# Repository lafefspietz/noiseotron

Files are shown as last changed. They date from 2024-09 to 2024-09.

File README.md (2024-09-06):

# NOISEOTRON

Open source instrument for measuring noise

 - [radio.html](radio.html)
 - [sinewave.html](sinewave.html)
 - [noiseband.html](noiseband.html)
 - [whitenoise.html](whitenoise.html)
 - [quantumnoisetriangle.html](quantumnoisetriangle.html)
 - [quantumsnow.html](quantumsnow.html)
 - [audiospectrum.html](audiospectrum.html)
 - [audiospectrum-2d.html](audiospectrum-2d.html)
 - [webeditor.html](webeditor.html)
 - [geometron/](geometron/)

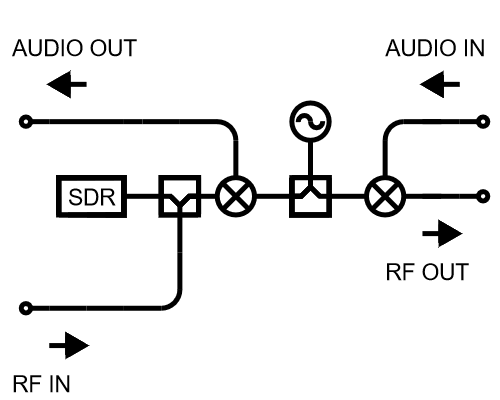
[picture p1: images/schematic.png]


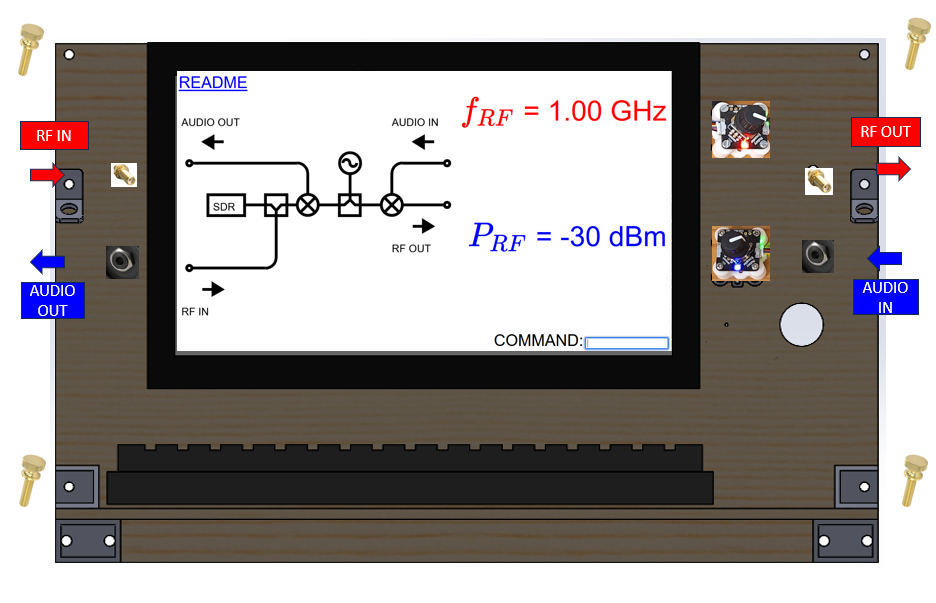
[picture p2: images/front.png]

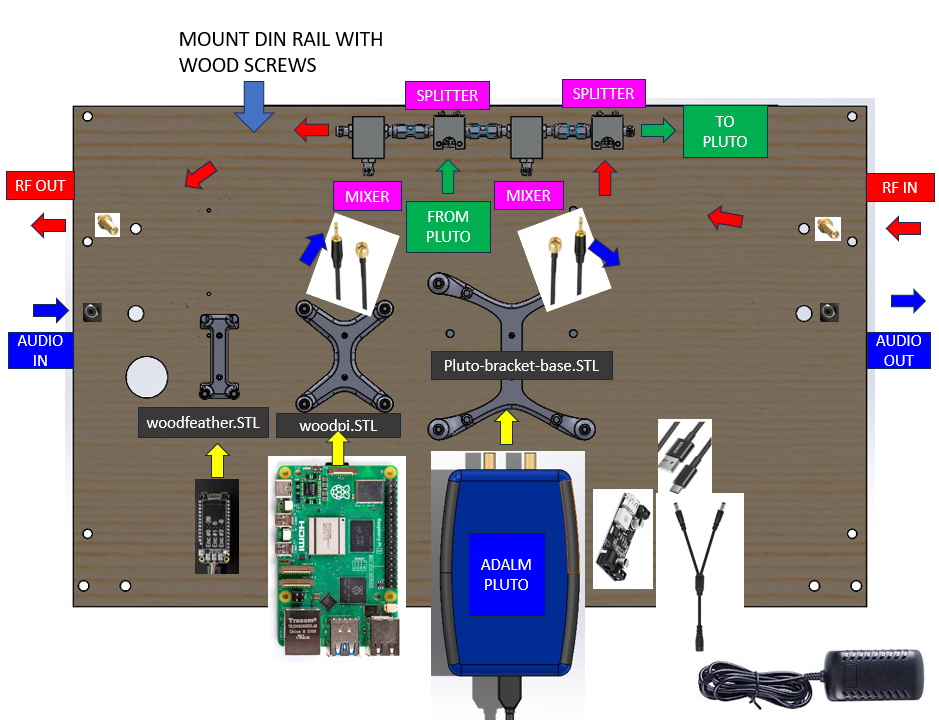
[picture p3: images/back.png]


# Bill of Materials

- [Adalm  Pluto SDR and RF source](https://www.analog.com/en/resources/evaluation-hardware-and-software/evaluation-boards-kits/adalm-pluto.html)
 - [Mini-Circuits ZFRSC-123-S+ 2 way Splitter DC-12 GHz, 50Ω x2](https://www.minicircuits.com/WebStore/dashboard.html?model=ZFRSC-123-S%2B)
 - [Mini-Circuits ZX05-C60-S+ Double Balanced Mixer x2](https://www.minicircuits.com/WebStore/dashboard.html?model=ZX05-C60-S%2B)
 - [Amphenol 132168 M-M SMA Barrel x3](https://www.digikey.com/en/products/detail/amphenol-rf/132168/1011917)
 - [SMA to 1/8" Audio Aux cable from Amazon x2](https://www.amazon.com/supmory-Stereo-Adapter-Antenna-Extension/dp/B0C9JBZ139/)
 - [Audio Panel Mount Feedthru(3/8" hole) x2](https://www.amazon.com/3-5mm-Stereo-Feed-Thru-Panel-Mount/dp/B004JX64FE/)
 - [8" SMA Cable x2](https://www.digikey.com/en/products/detail/crystek-corporation/CCSMA-MM-086-8/2683937)
 - [SMA Panel Mount Feedthru(1/4" hole) x2](https://www.digikey.com/en/products/detail/te-connectivity-linx/ADP-SMAF-SMAF-B-G/11314389)
 - [12"x24" pine board x2](https://www.amazon.com/AWIZOM-Unfinished-Wood-Pine-Rectangular/dp/B0CYQ5PZQX/)
 - [10-32 knurled brass thumb screw x4](https://www.mcmaster.com/92421A645/)
 - [13" wide HDMI Screen from Sunfounder x1](https://www.sunfounder.com/collections/displays-touchscreens-for-raspberry-pi/products/13inch-portable-gaming-monitor)
 - [USB A to C power cable x1](https://www.newegg.com/p/0S8-014F-00215)
 - [12 V to 5 V converter x1](https://www.newegg.com/p/36F-009H-002Z0)
 - [12 V barrel splitter x1](https://www.batteryeliminatorkits.com/product-p/1x2-splitter-cable-long.htm)
 - [Sparkfun QWIIC kit x1](https://www.sparkfun.com/products/15081)
 - [Raspberry Pi 5](https://www.digikey.com/en/products/detail/raspberry-pi/SC1110/24627138)
 - [narrow keyboard](https://www.amazon.com/SR-Keyboard-Multimedia-Computer-Laptop/dp/B01IQL2VCE/)
 - [mouse](https://www.amazon.com/TECKNET-6-Button-Ergonomic-Chromebook-Notebook-Grey/dp/B01BC4TXXC/)
 - [M2.5 Thread inserts](https://www.3djake.com/ruthex/threaded-insert-m25-70-pieces)
 - [M2.5 Screws](https://www.homedepot.com/p/Prime-Line-M2-5-0-45-x-8-mm-Metric-Zinc-Plated-Steel-Phillips-Drive-Pan-Head-Machine-Screws-25-Pack-9130839/311229788)
 - #4 wood screws()
 - [Adafruit Feather](https://www.adafruit.com/product/5300)
 - [Adafruit encoder knob](https://www.adafruit.com/product/4991)

## 3d printed parts

 - [woodpi.STL (x1)]()
 - [woodfeather.STL (x1)]()
 - [stemma-knob-wood-bracket.STL(x2)]()
 - [pluto-bracket-base.STL (x1)]()
 - [pluto-bracket-top-bar.STL (x2)]()
 - [wood-angle-bracket.STL (x2)]()
 - [wood-peg.STL(x6)]()
 - [string-anchor.STL(x2)]()

## stemma-knob-wood-bracket.*

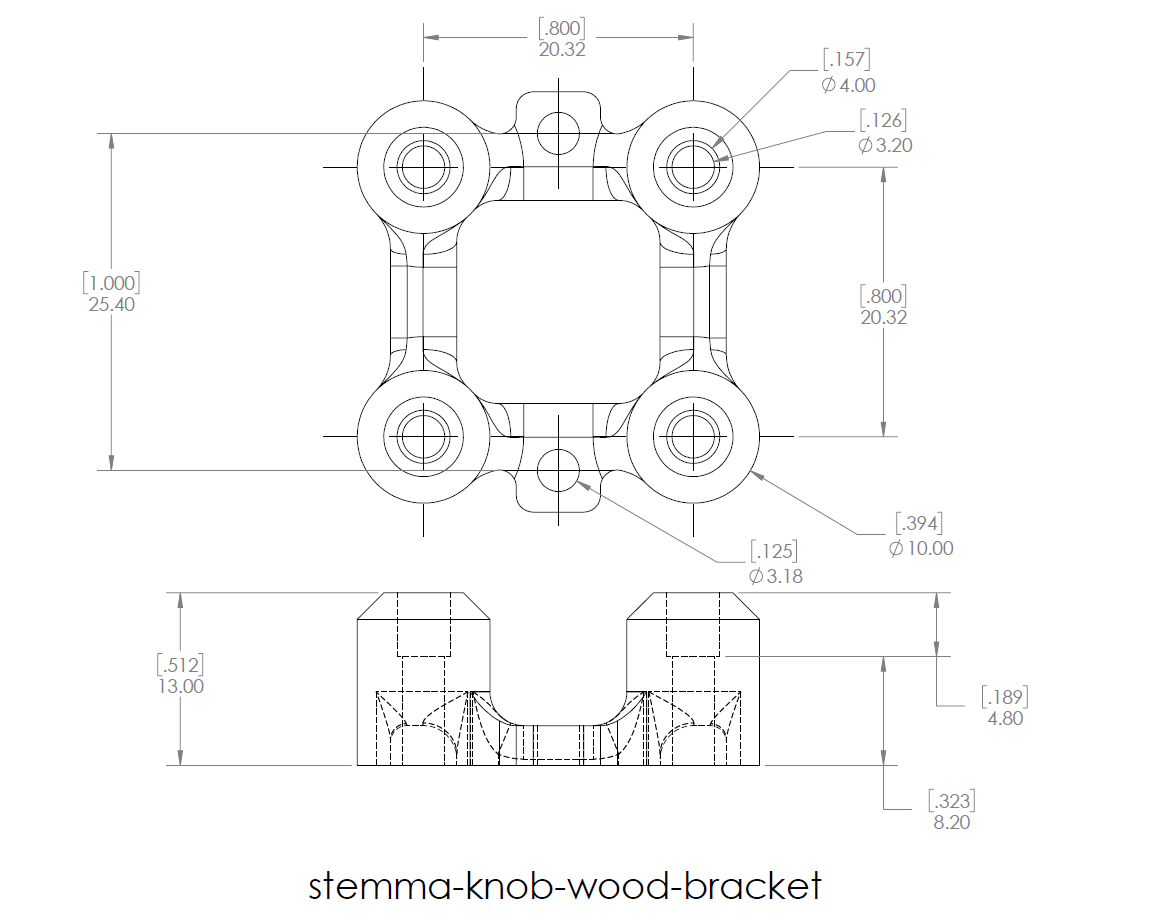
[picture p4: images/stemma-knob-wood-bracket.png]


 - [3dprint/stemma-knob-wood-bracket.STL](3dprint/stemma-knob-wood-bracket.STL)
 - [3dprint/stemma-knob-wood-bracket.SLDPRT](3dprint/stemma-knob-wood-bracket.SLDPRT)
 - [3dprint/stemma-knob-wood-bracket.SLDDRW](3dprint/stemma-knob-wood-bracket.SLDDRW)
 - [3dprint/stemma-knob-wood-bracket.pdf](3dprint/stemma-knob-wood-bracket.pdf)

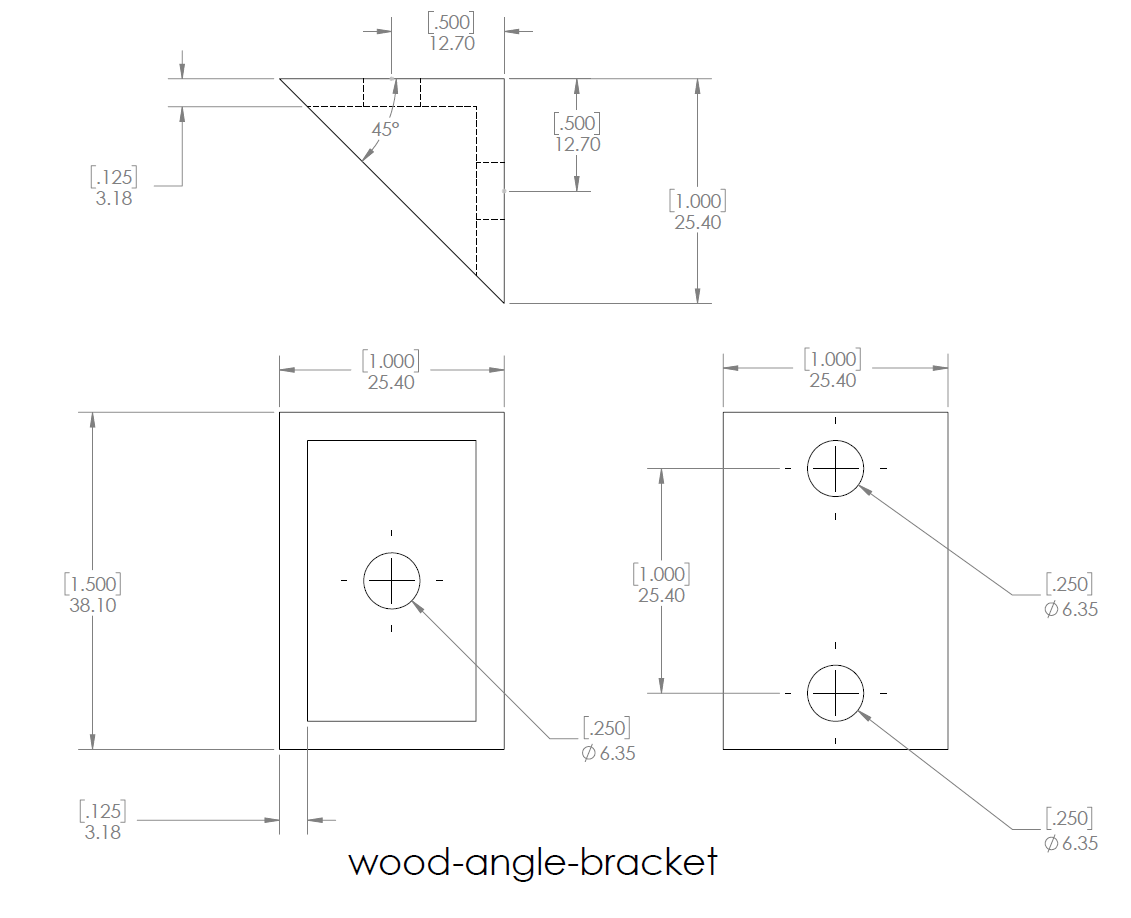
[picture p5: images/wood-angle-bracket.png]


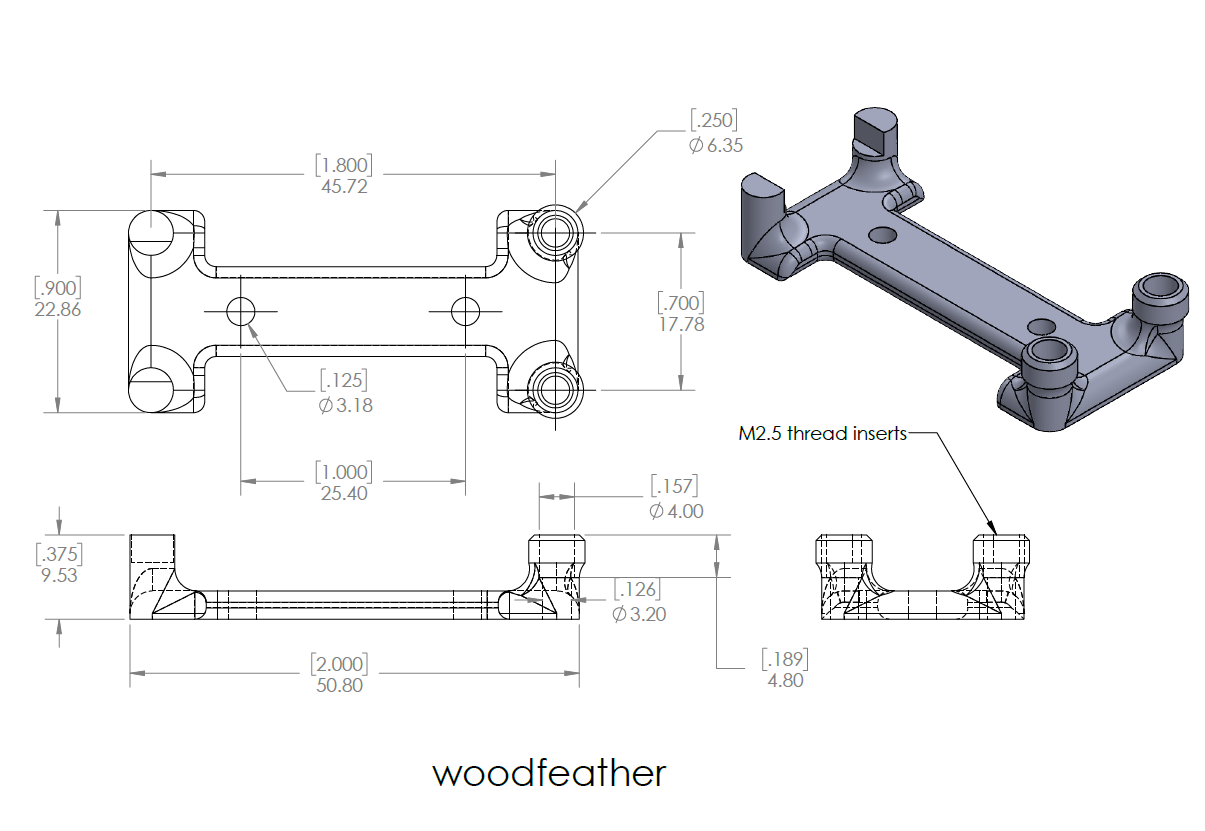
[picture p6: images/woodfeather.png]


# Feather code

 - [All files that go in lib folder in lib.zip](circuitpython/lib.zip)
 - [code.py](circuitpython/code.py)

## Code.py

```

# SPDX-FileCopyrightText: 2021 John Park
# SPDX-License-Identifier: MIT

# I2C rotary encoder multiple test example.
# solder the A0 jumper on the second QT Rotary Encoder board
import time

import board
from adafruit_seesaw import seesaw, rotaryio, digitalio, neopixel
import usb_hid
from adafruit_hid.keyboard import Keyboard
from adafruit_hid.keyboard_layout_us import KeyboardLayoutUS
from adafruit_hid.keycode import Keycode
running = False
# The keyboard object!
time.sleep(1)  # Sleep for a bit to avoid a race condition on some systems
keyboard = Keyboard(usb_hid.devices)
keyboard_layout = KeyboardLayoutUS(keyboard)  # We're in the US :)

i2c = board.I2C()  # uses board.SCL and board.SDA
# i2c = board.STEMMA_I2C()  # For using the built-in STEMMA QT connector on a microcontroller

qt_enc1 = seesaw.Seesaw(i2c, addr=0x36)
qt_enc2 = seesaw.Seesaw(i2c, addr=0x37)

qt_enc1.pin_mode(24, qt_enc1.INPUT_PULLUP)
button1 = digitalio.DigitalIO(qt_enc1, 24)
button_held1 = False

qt_enc2.pin_mode(24, qt_enc2.INPUT_PULLUP)
button2 = digitalio.DigitalIO(qt_enc2, 24)
button_held2 = False

encoder1 = rotaryio.IncrementalEncoder(qt_enc1)
last_position1 = None

encoder2 = rotaryio.IncrementalEncoder(qt_enc2)
last_position2 = None

pixel1 = neopixel.NeoPixel(qt_enc1, 6, 1)
pixel1.brightness = 0.05
pixel1.fill(0xff0000)

pixel2 = neopixel.NeoPixel(qt_enc2, 6, 1)
pixel2.brightness = 0.02
pixel2.fill(0x0000ff)

while True:

    # negate the position to make clockwise rotation positive
    position1 = -encoder1.position
    position2 = -encoder2.position

    if position1 != last_position1:
        last_position1 = position1
        print("Position 1: {}".format(position1))
        keyboard_layout.write("red={}\n".format(position1))

    if not button1.value and not button_held1:
        button_held1 = True
        pixel1.brightness = 0.5
        print("Button 1 pressed")
        keyboard_layout.write("redpress\n")

    if button1.value and button_held1:
        button_held1 = False
        pixel1.brightness = 0.2
        print("Button 1 released")

    if position2 != last_position2:
        last_position2 = position2
        print("Position 2: {}".format(position2))
        keyboard_layout.write("blue={}\n".format(position2))

    if not button2.value and not button_held2:
        button_held2 = True
        pixel2.brightness = 0.5
        print("Button 2 pressed")
        keyboard_layout.write("bluepress\n")

    if button2.value and button_held2:
        button_held2 = False
        pixel2.brightness = 0.2
        print("Button 2 released")

```

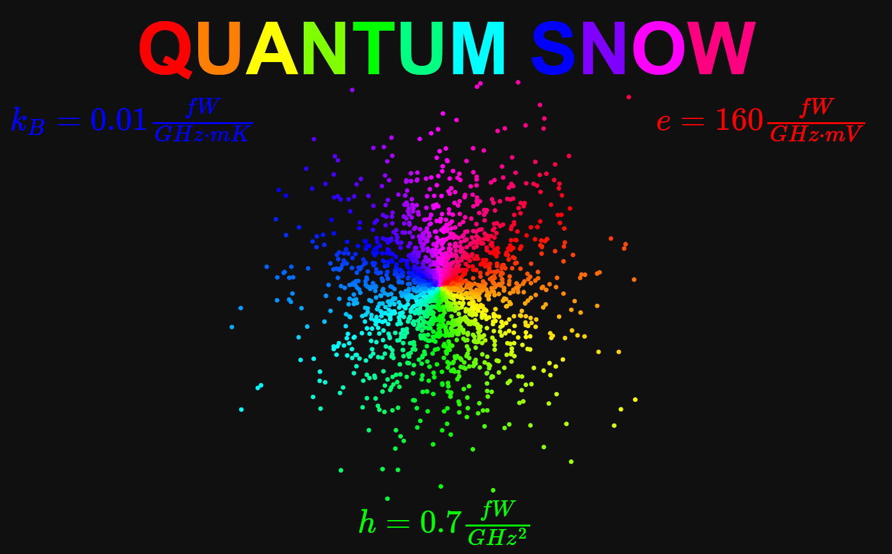
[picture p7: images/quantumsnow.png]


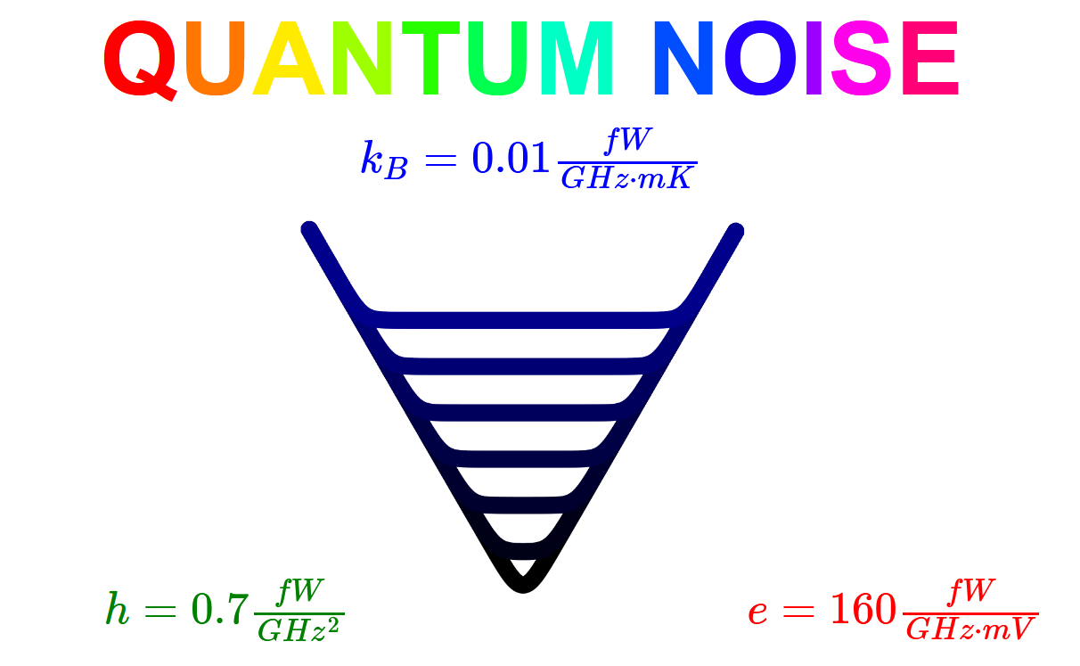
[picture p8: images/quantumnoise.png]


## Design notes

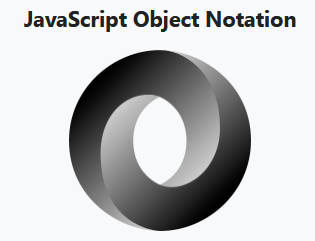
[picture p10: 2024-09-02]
images/json.png

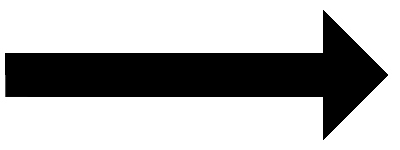
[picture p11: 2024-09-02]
images/longarrow.png

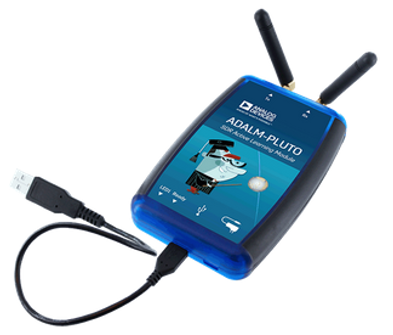
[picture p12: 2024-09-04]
images/pluto.png

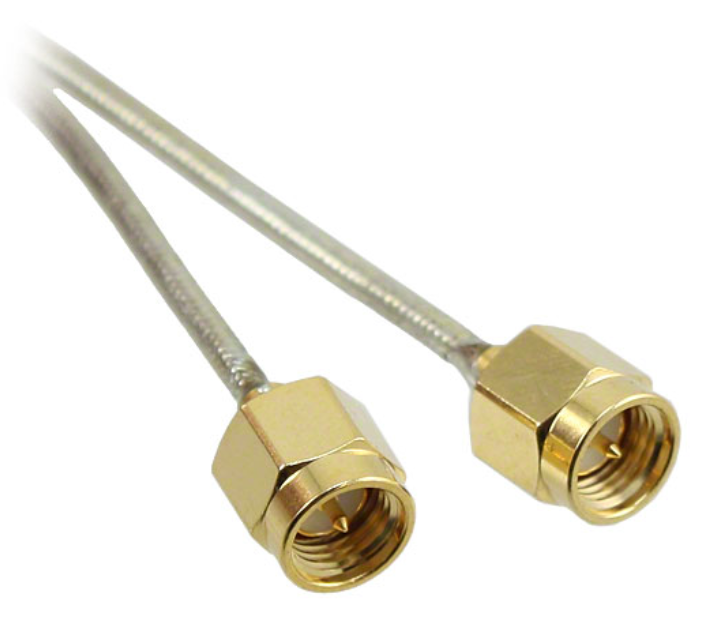
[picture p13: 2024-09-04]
images/sma.png

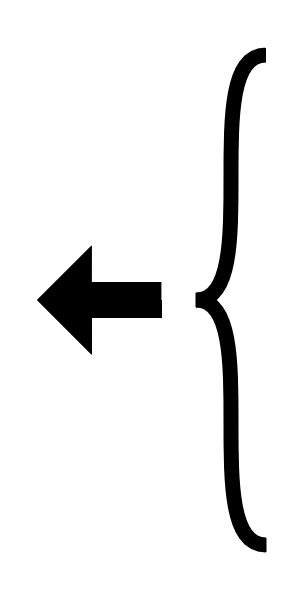
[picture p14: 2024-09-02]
images/joinarrow.png

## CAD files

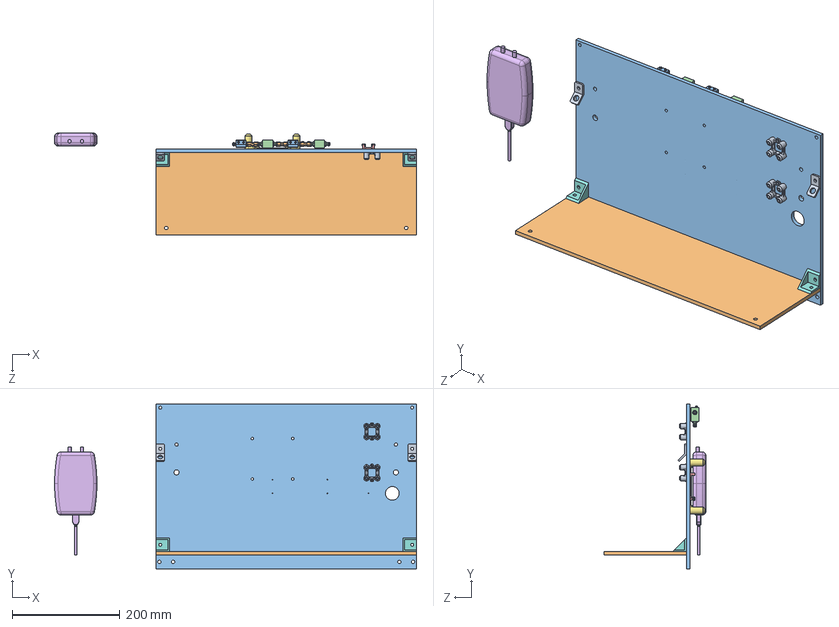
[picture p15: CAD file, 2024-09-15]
rack-mount-assembly.SLDASM
670.6 x 304.8 x 188.3 mm
rack-mount-panel
keyboard-shelf
stemma-knob-wood-bracket x 2
wood-angle-bracket-top x 2
pluto-bracket-base
pluto-box-model
woodfeather
splitter-JJJ245 x 2
mixer-FL905(E) x 2
SMA-barrel-M-M-132168 x 3
string-anchor x 2

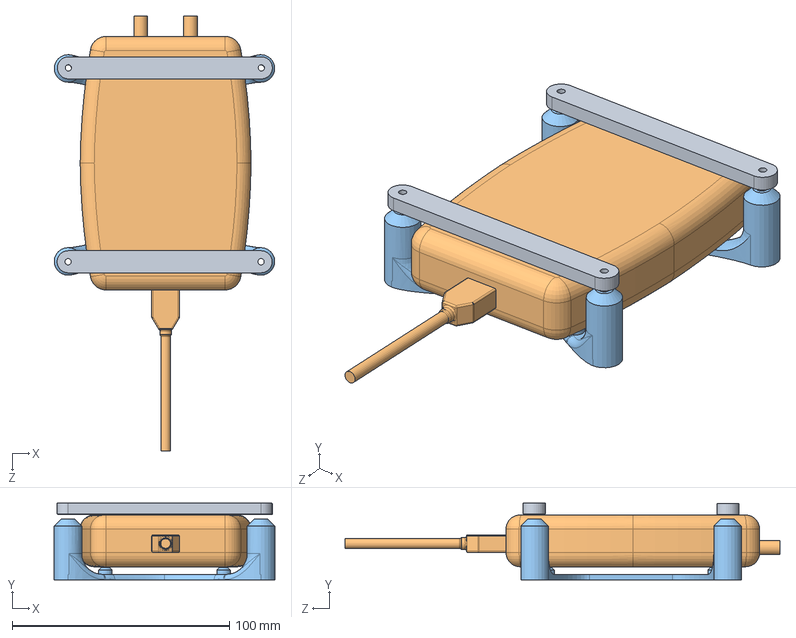
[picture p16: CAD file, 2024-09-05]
pluto-bracket-assembly.SLDASM
101.6 x 35.3 x 200.4 mm
pluto-bracket-base
pluto-box-model
pluto-bracket-top-bar x 2

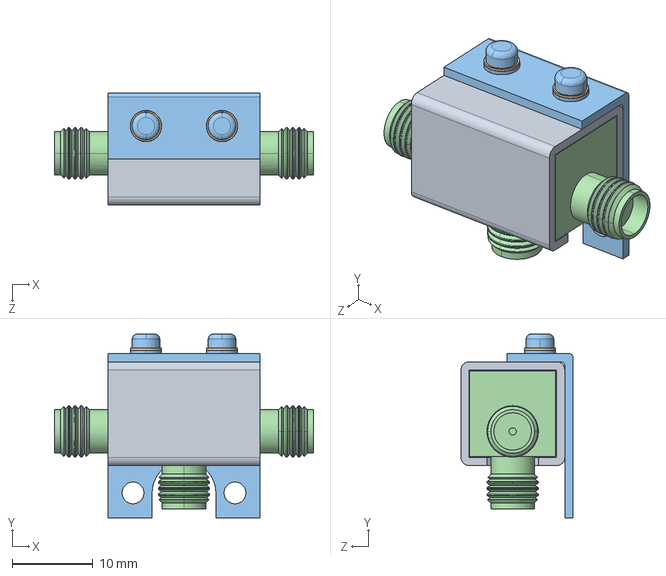
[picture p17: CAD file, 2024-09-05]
3dmodel/FL905(E).STEP
32.0 x 22.7 x 13.8 mm

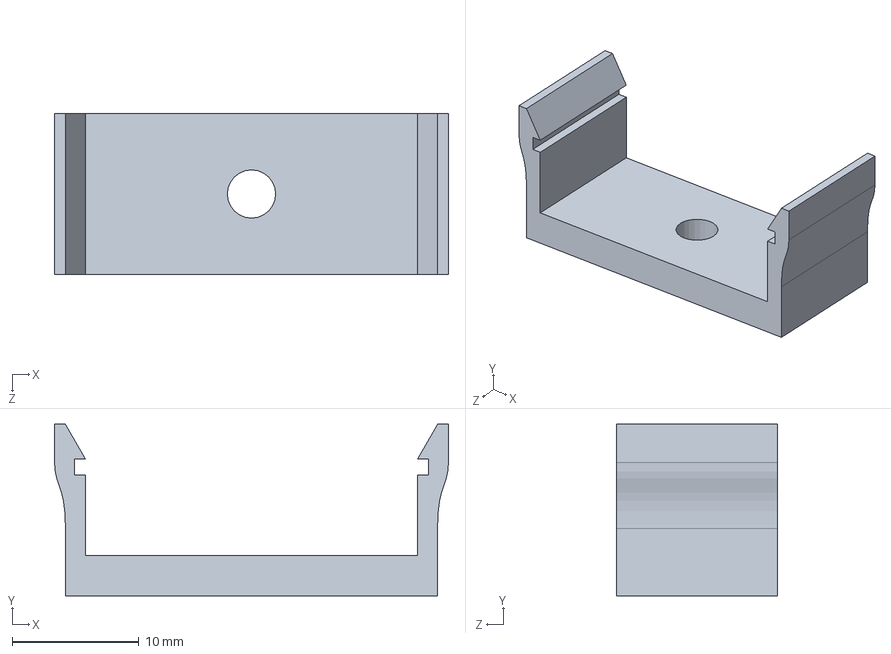
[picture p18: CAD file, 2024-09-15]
3dprint/drok-bracket.SLDPRT
31.1 x 13.5 x 12.7 mm

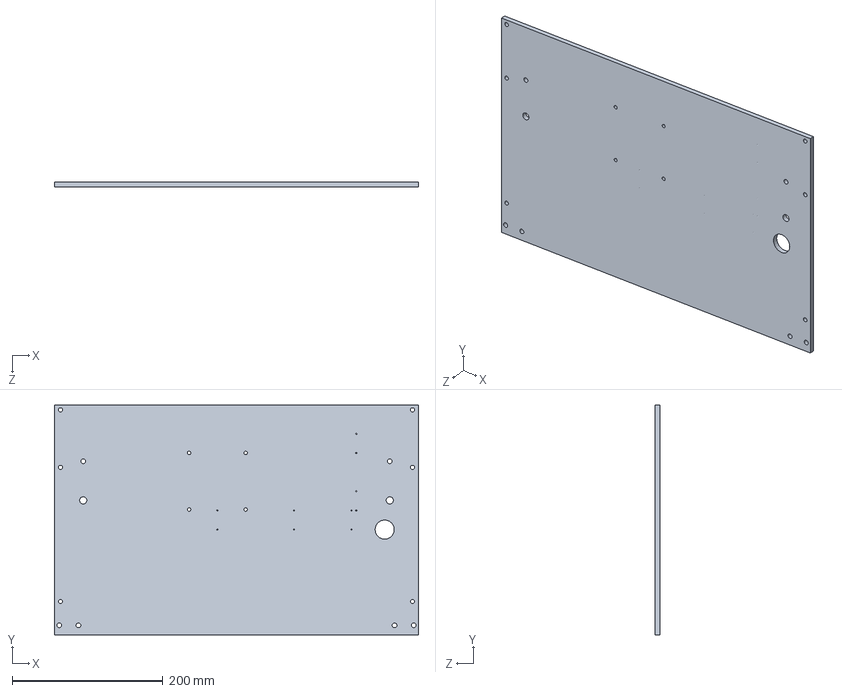
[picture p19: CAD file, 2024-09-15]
wood/rack-mount-panel.SLDPRT
482.6 x 304.8 x 6.35 mm

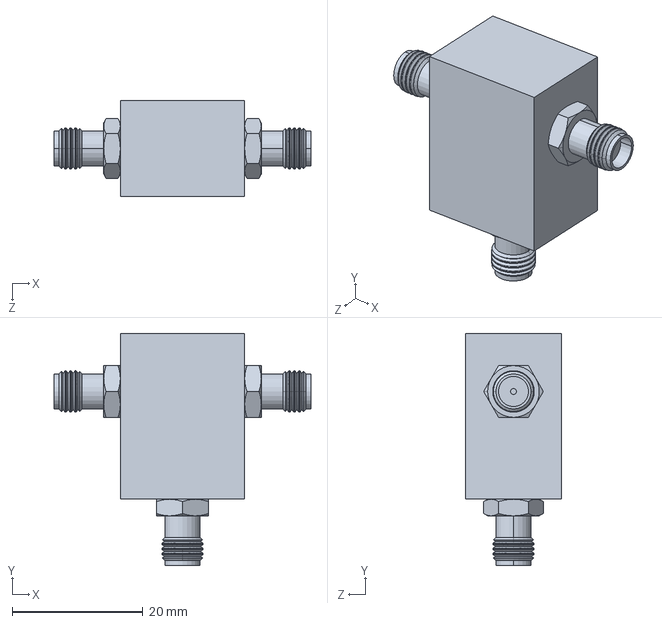
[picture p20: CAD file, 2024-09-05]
3dmodel/splitter-JJJ245.SLDPRT
39.4 x 35.6 x 14.7 mm

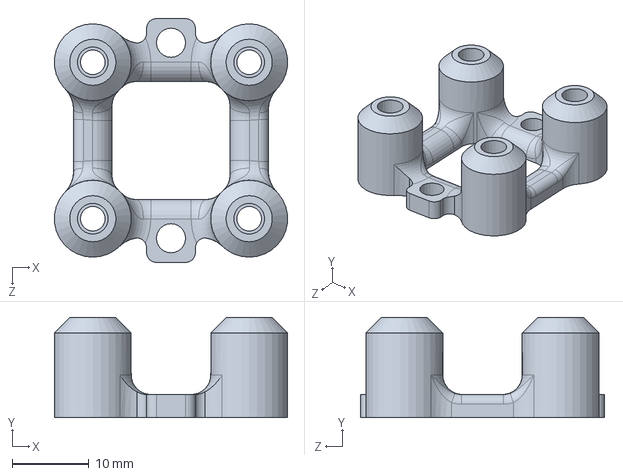
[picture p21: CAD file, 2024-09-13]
3dprint/stemma-knob-wood-bracket.SLDPRT
30.3 x 13.0 x 31.7 mm

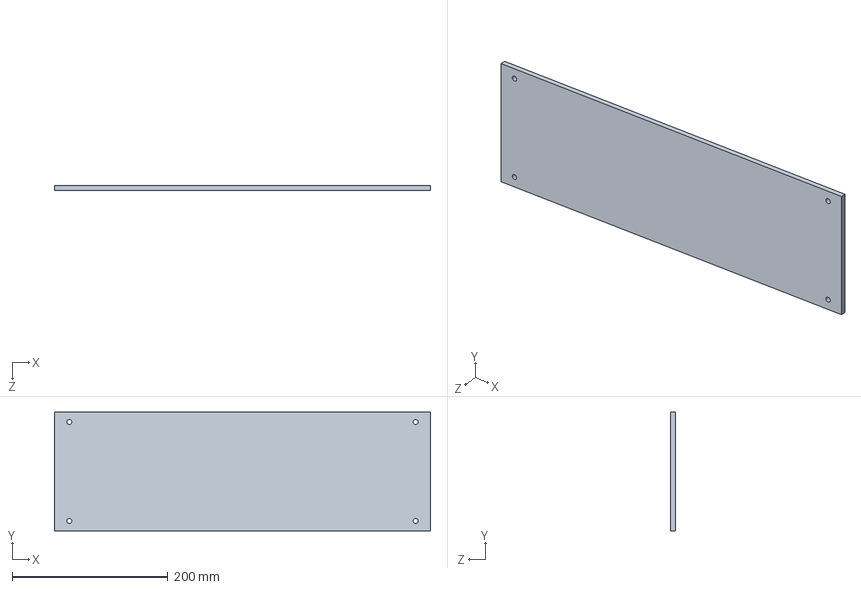
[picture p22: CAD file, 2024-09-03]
wood/keyboard-shelf.SLDPRT
482.6 x 152.4 x 6.35 mm

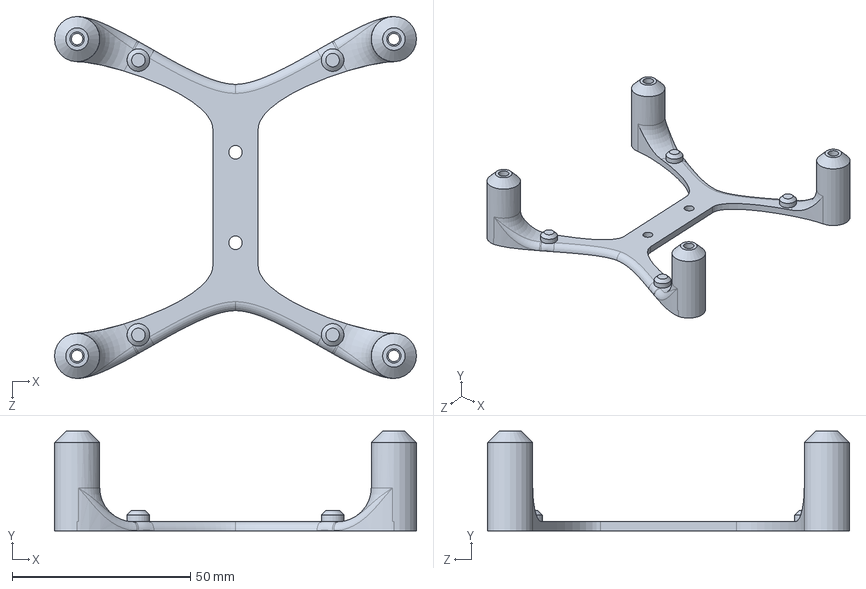
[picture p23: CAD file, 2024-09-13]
3dprint/pluto-bracket-base.SLDPRT
101.6 x 27.9 x 101.6 mm

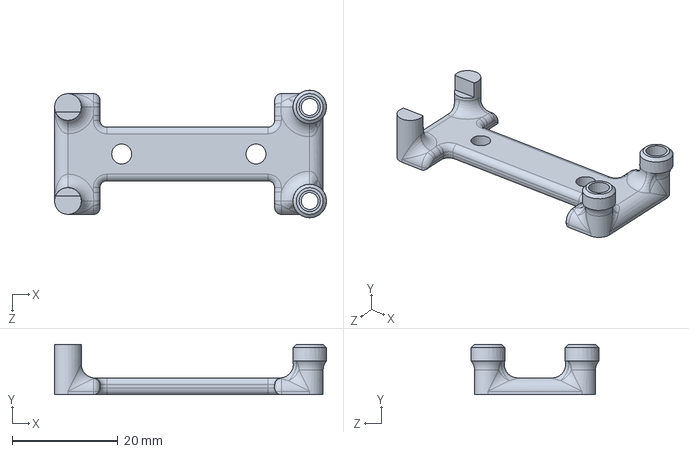
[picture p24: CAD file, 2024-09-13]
3dprint/woodfeather.SLDPRT
51.4 x 9.53 x 24.1 mm

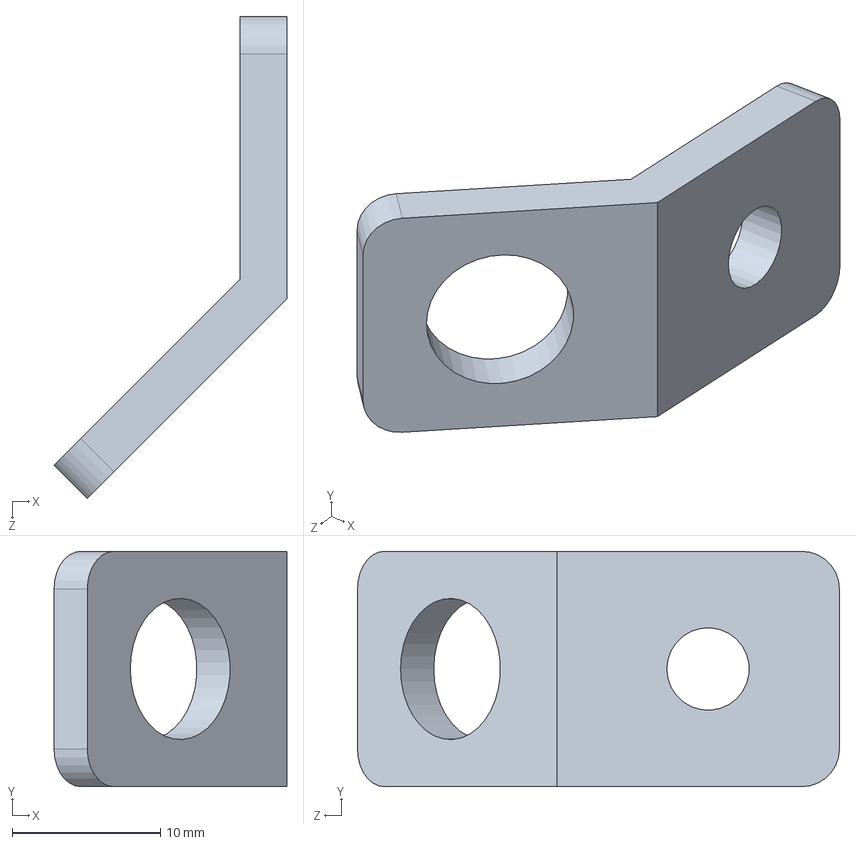
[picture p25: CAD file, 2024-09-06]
3dprint/string-anchor.SLDPRT
15.7 x 15.9 x 32.5 mm

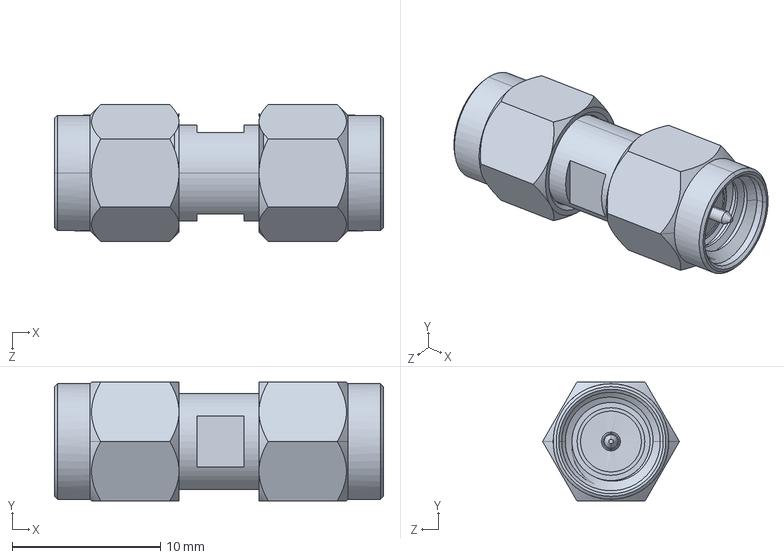
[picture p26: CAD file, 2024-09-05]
3dmodel/SMA-barrel-M-M-132168.SLDPRT
22.2 x 8.00 x 9.24 mm

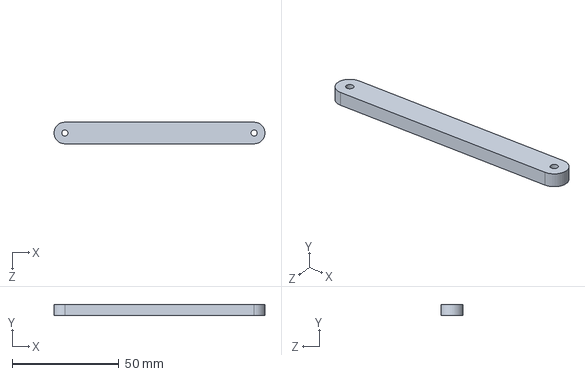
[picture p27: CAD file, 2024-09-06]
3dprint/pluto-bracket-top-bar.SLDPRT
99.1 x 5.08 x 10.2 mm

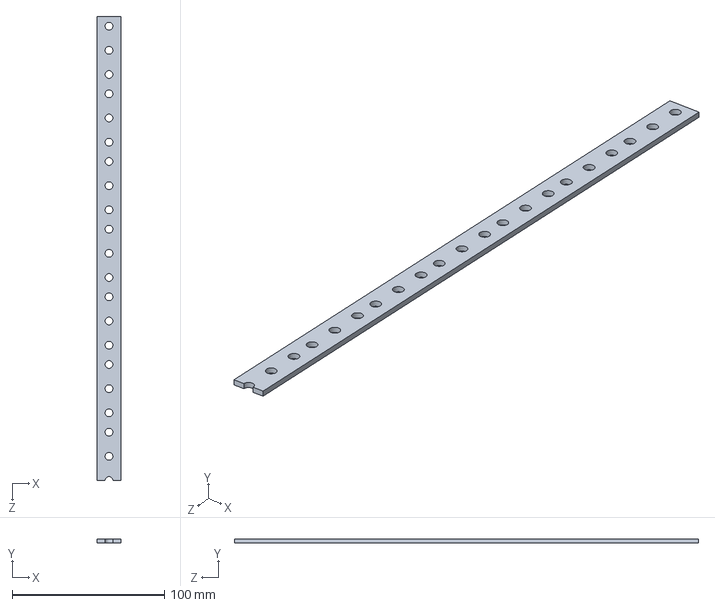
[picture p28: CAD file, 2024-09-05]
3dmodel/rack-side-holes-model.SLDPRT
15.9 x 2.54 x 304.8 mm

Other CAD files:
3dmodel/JJJ245.STEP
3dmodel/mixer-FL905(E).SLDPRT
3dprint/wood-angle-bracket-top.SLDPRT
3dmodel/pluto-box-model.SLDPRT
3dmodel/132168.stp
3dmodel/5300 ESP32-S2 TFT Feather.SLDDRW
3dmodel/5300 ESP32-S2 TFT Feather.step
3dmodel/5300 ESP32-S2 TFT Feather.stl
3dmodel/keyboard.SLDPRT
3dmodel/paracord.SLDPRT
3dmodel/pluto-box-model.SLDDRW
3dmodel/rack-side-holes-model.SLDDRW
3dmodel/screen.SLDPRT
3dprint/drok-bracket.STL
3dprint/pluto-bracket-base.SLDDRW
3dprint/pluto-bracket-base.STL
3dprint/pluto-bracket-top-bar.SLDDRW
3dprint/pluto-bracket-top-bar.STL
3dprint/stemma-knob-wood-bracket.SLDDRW
3dprint/stemma-knob-wood-bracket.STL
3dprint/string-anchor.SLDDRW
3dprint/wood-angle-bracket-top.STL
3dprint/wood-angle-bracket.SLDDRW
3dprint/wood-angle-bracket.SLDPRT
3dprint/wood-angle-bracket.STL
3dprint/wood-peg.SLDDRW
3dprint/wood-peg.SLDPRT
3dprint/wood-peg.STL
3dprint/woodfeather.SLDDRW
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

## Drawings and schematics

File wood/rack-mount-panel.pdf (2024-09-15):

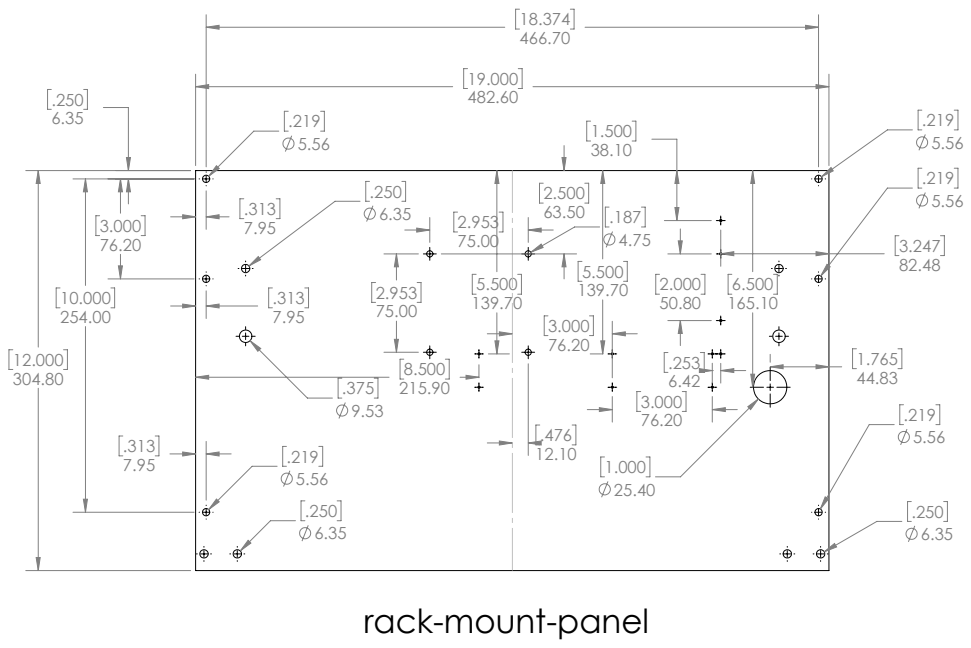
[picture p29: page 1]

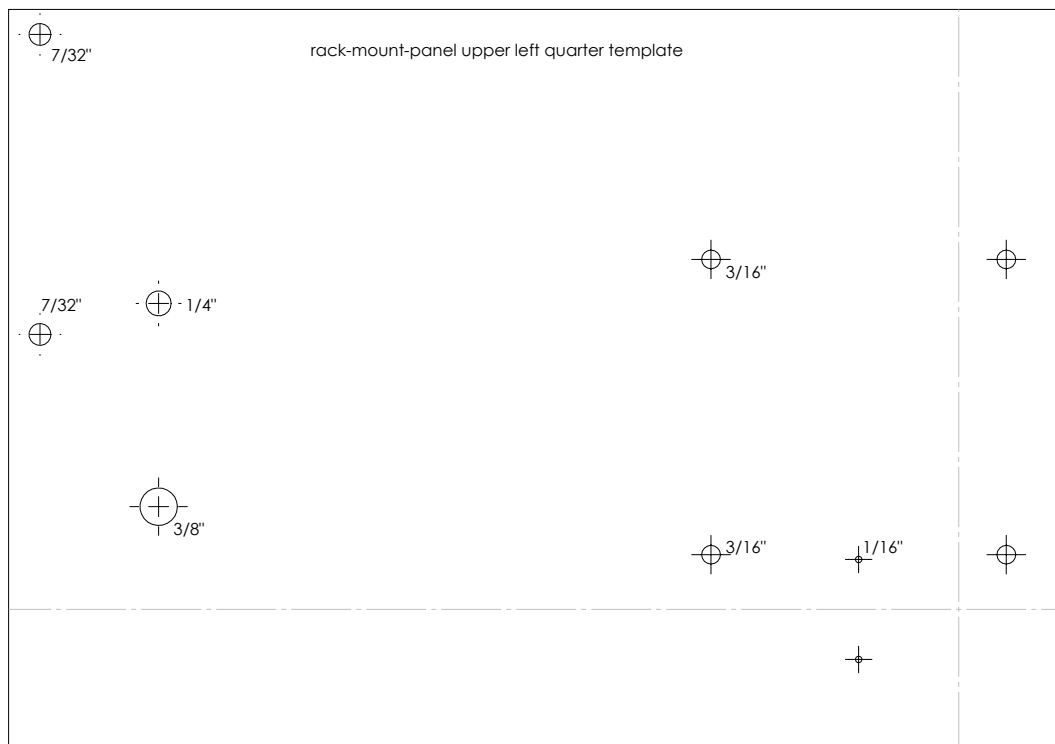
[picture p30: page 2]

rack-mount-panel upper left quarter template

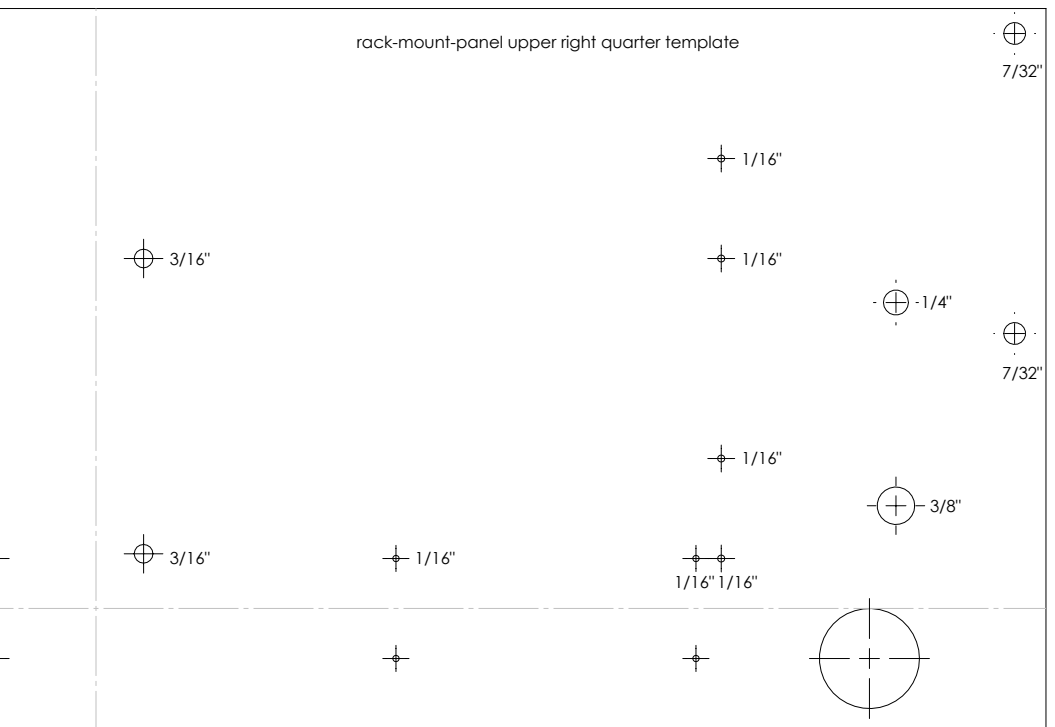
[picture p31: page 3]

rack-mount-panel upper right quarter template

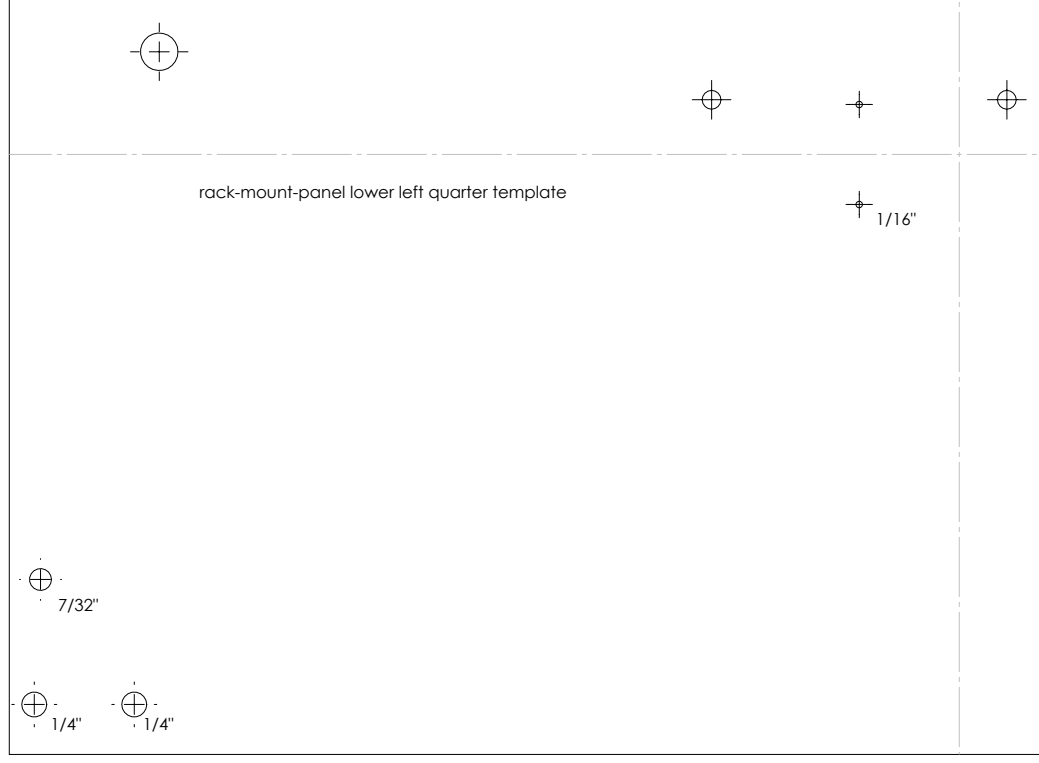
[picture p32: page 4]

rack-mount-panel lower left quarter template

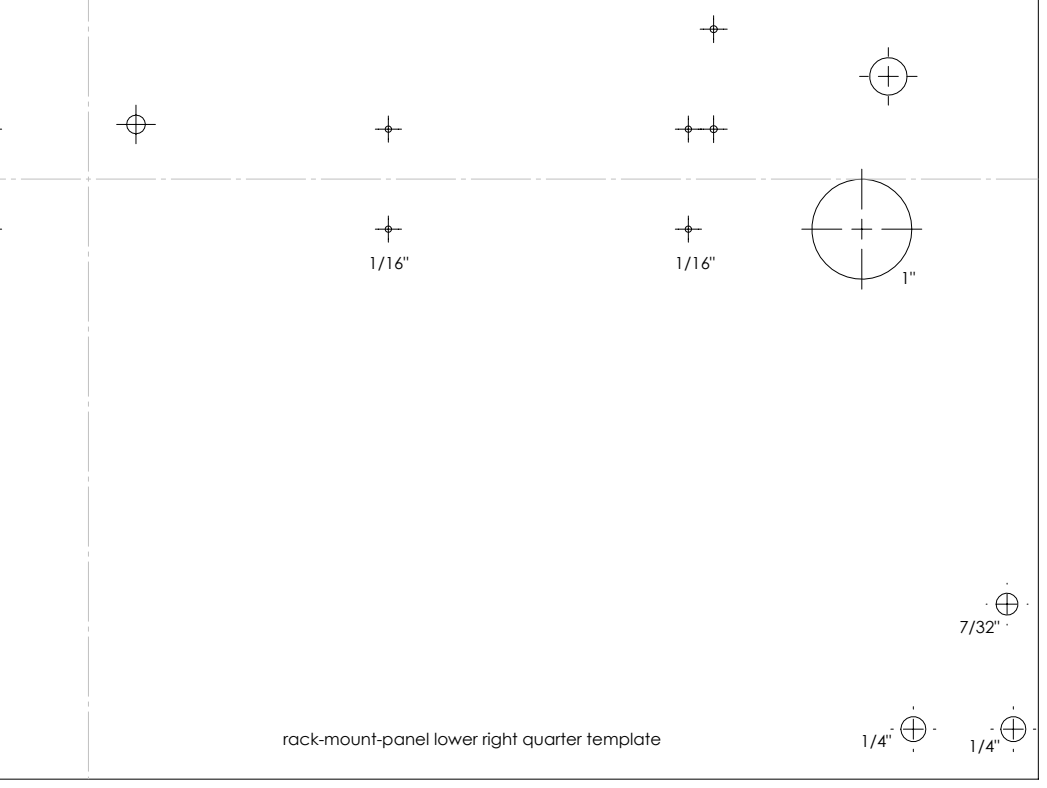
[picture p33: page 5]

rack-mount-panel lower right quarter template

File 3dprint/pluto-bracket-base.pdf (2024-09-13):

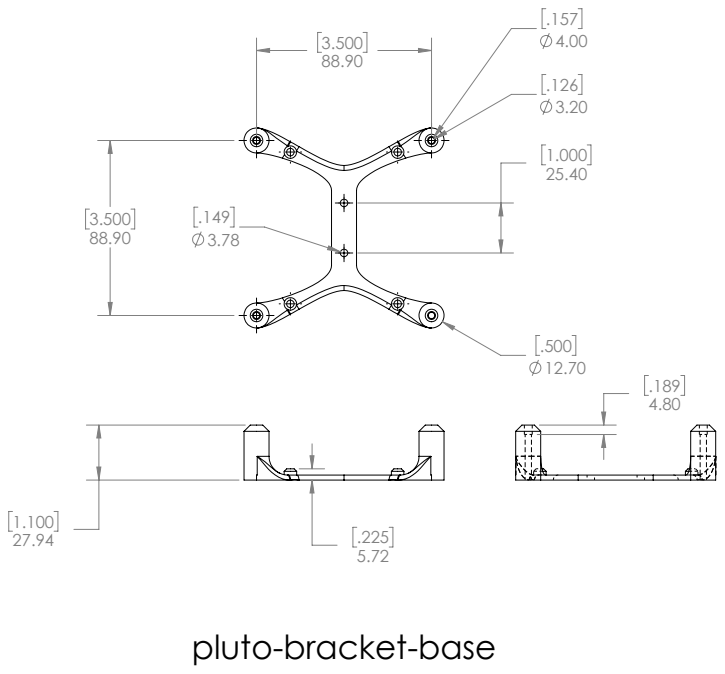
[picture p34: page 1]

pluto-bracket-base

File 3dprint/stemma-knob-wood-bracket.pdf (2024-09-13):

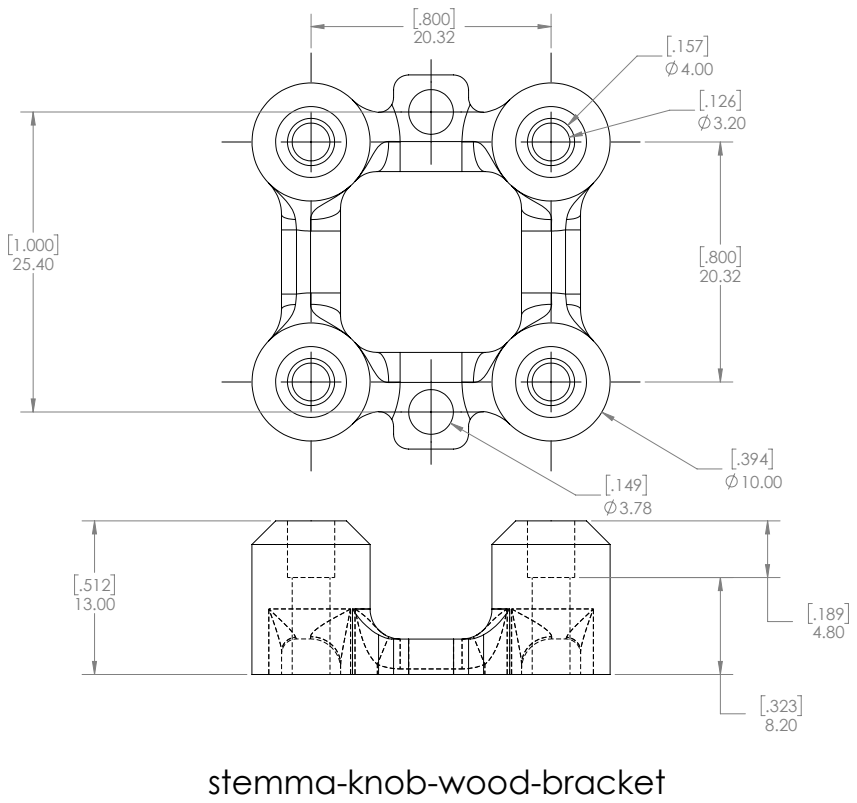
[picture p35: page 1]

stemma-knob-wood-bracket

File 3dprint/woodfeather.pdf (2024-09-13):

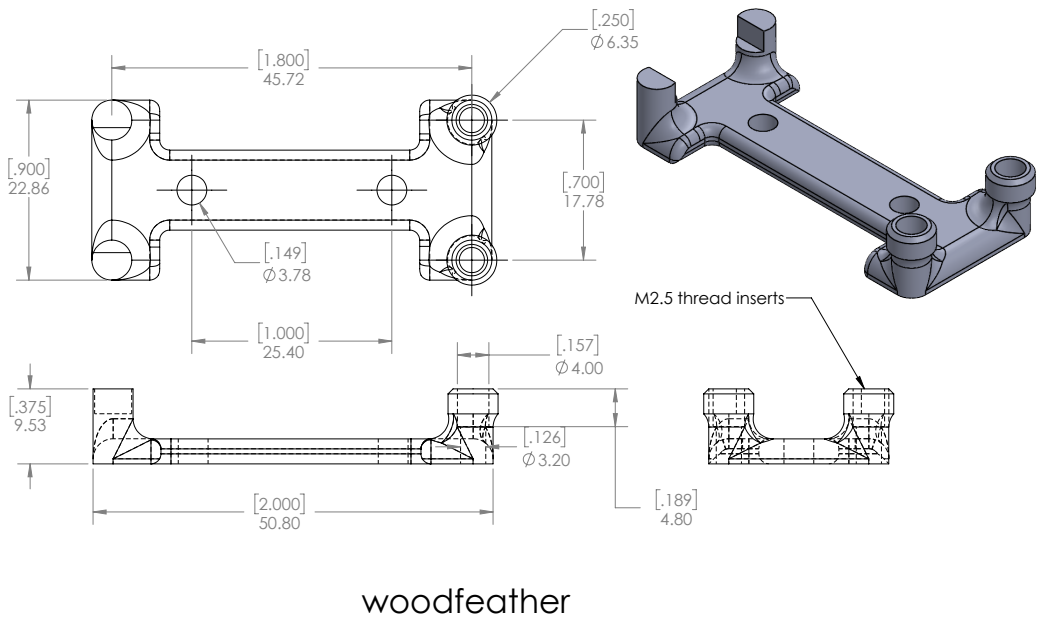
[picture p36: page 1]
M2.5 thread inserts

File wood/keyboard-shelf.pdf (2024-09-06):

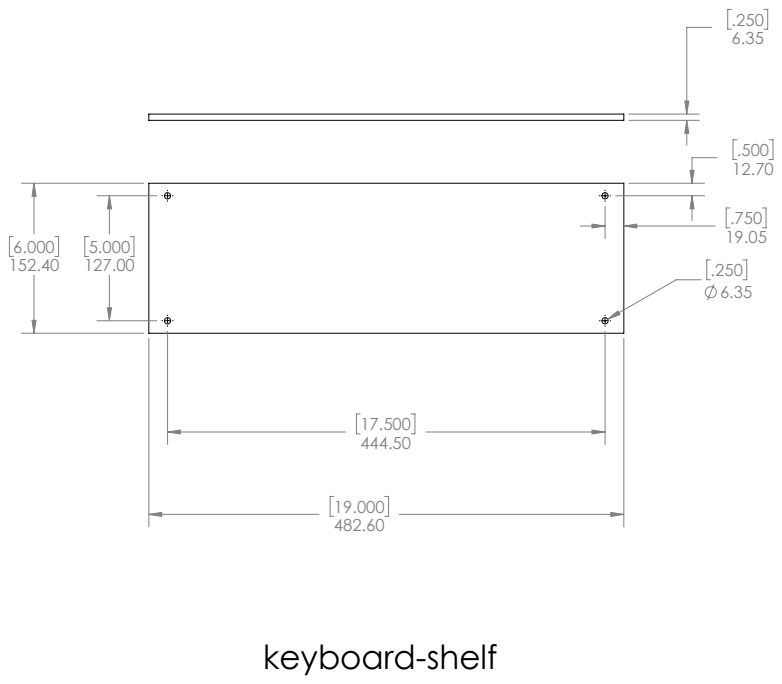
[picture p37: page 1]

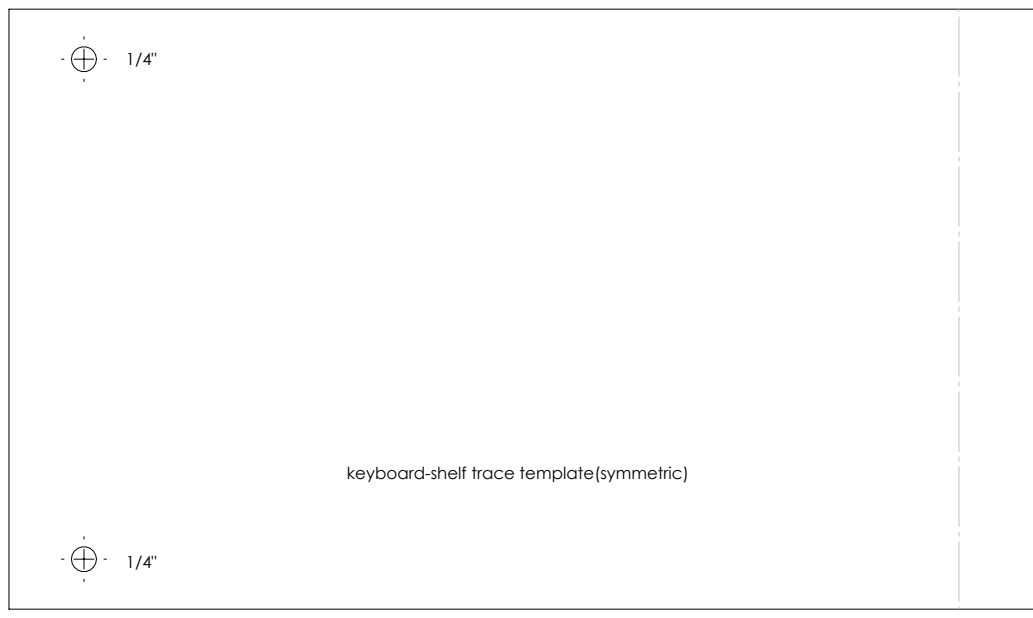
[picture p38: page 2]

keyboard-shelf trace template(symmetric)

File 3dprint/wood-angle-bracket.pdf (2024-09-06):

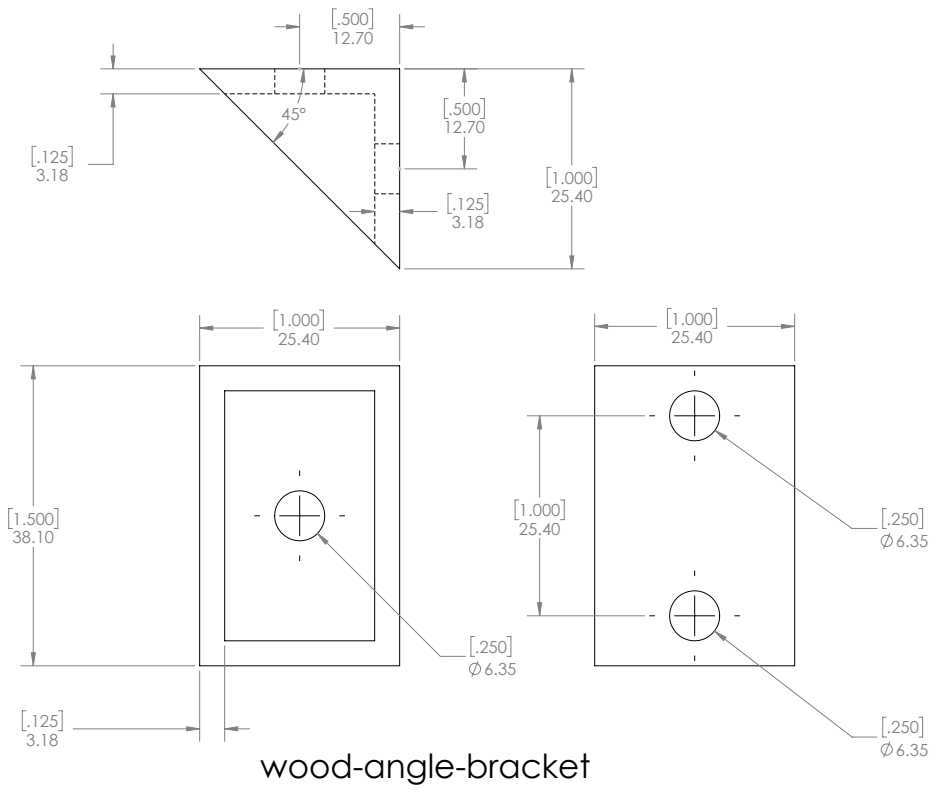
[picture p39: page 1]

wood-angle-bracket

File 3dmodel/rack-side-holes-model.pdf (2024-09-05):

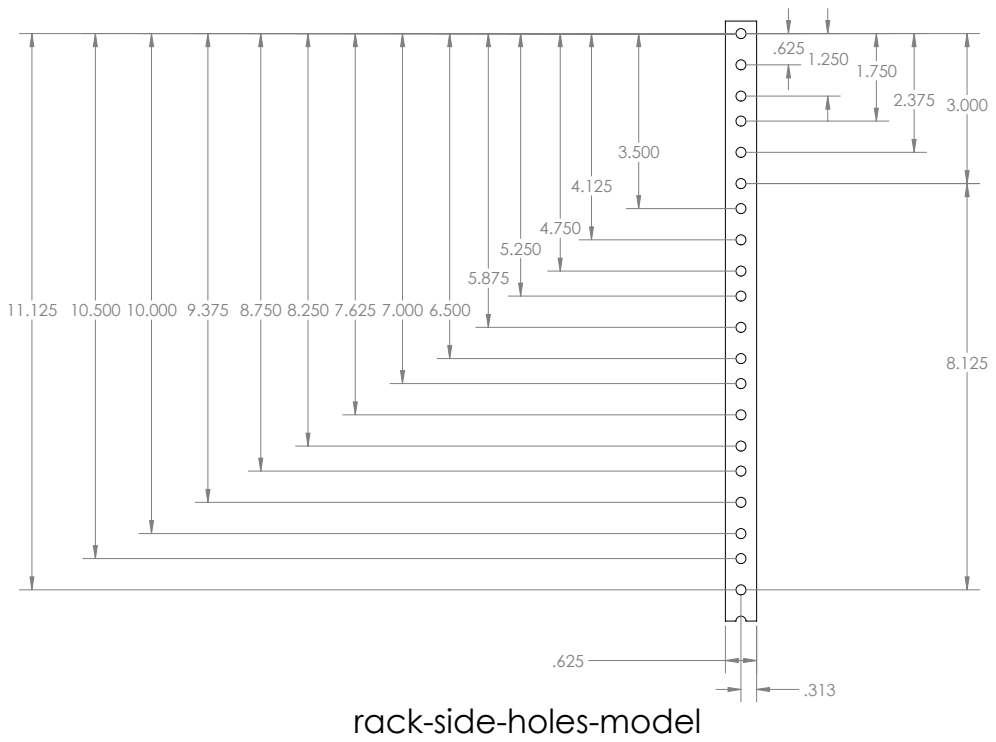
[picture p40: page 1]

rack-side-holes-model





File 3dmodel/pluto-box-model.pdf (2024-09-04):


pluto-box-model

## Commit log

2024-09-02 noiseotron has working knob control
    [5300 ESP32-S2 TFT Feather.SLDDRW, 5300 ESP32-S2 TFT Feather.step, 5300 ESP32-S2 TFT Feather.stl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]
2024-09-03 copying more of noise radio into noiseotron
    [keyboard-shelf.SLDPRT, rack-mount-assembly.SLDASM, rack-mount-panel.SLDPRT]
2024-09-03 lots of graphics tweaks
    [rack-mount-assembly.SLDASM, rack-mount-panel.SLDPRT, stemma-knob-wood-bracket.SLDPRT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]
2024-09-03 putting it all together
    [stemma-knob-wood-bracket.SLDDRW, stemma-knob-wood-bracket.STL]
2024-09-04 putting the bill of materials into the README
2024-09-04 drawing for peg which goes into angle bracket
    [wood-peg.SLDDRW]
2024-09-04 design of brackets for pluto
    [pluto-box-model.SLDDRW, pluto-bracket-assembly.SLDASM, pluto-bracket-base.SLDPRT]
2024-09-05 pluto bracket work
    [pluto-bracket-assembly.SLDASM, pluto-bracket-base.SLDPRT, pluto-bracket-top-bar.SLDPRT]
2024-09-05 rack panel hole pattern modeling
    [rack-mount-panel.SLDPRT, rack-side-holes-model.SLDDRW, rack-side-holes-model.SLDPRT]
2024-09-05 wood angle bracket design
    [rack-mount-assembly.SLDASM, wood-angle-bracket-top.SLDPRT]
2024-09-05 adding lots of documentation and improving fft app
    [132168.stp, FL905(E).STEP, JJJ245.STEP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]
2024-09-06 extensive work on drawings
    [pluto-bracket-base.SLDDRW, pluto-bracket-top-bar.SLDDRW, pluto-bracket-top-bar.SLDPRT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]
2024-09-06 added pdf drawings of wood parts
    [keyboard-shelf.SLDDRW, rack-mount-panel.SLDDRW]
2024-09-13 updated wood pi bracket to use #6 screws instead of #4 because 4's are stripping and annoying to buy
    [woodpi.SLDDRW, woodpi.SLDPRT, woodpi.STL]
2024-09-13 update all wood screws from #4 to #6
    [pluto-bracket-base.SLDDRW, pluto-bracket-base.SLDPRT, pluto-bracket-base.STL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]
2024-09-15 added bracket for dc dc converter and more dimensions to wood board drawing
    [drok-bracket.SLDPRT, drok-bracket.STL, rack-mount-assembly.SLDASM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]
2024-09-15 more dimensions for wood board pdf
    [rack-mount-panel.SLDDRW]
